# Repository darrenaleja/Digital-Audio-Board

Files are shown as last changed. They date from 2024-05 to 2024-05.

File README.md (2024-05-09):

# Digital Audio Board

## Table of Contents

- [Branch Information](#branch-information)
- [Project Overview](#project-overview)
- [PCB Design Highlights](#pcb-design-highlights)

## Branch Information

- **improvements**: Ongoing updates and enhancements to the initial PCB design are made in this branch. It includes comprehensive revisions in terms of circuit design and layout optimizations.
- **old-iteration**: This branch hosts the original PCB files that were submitted for manufacturing. It represents the first complete design iteration of the audio board.

## Project Overview

I developed this digital audio board to handle and playback digital audio. This repository contains the circuit design, PCB project, datasheets, and detailed documentation needed to understand the digital audio processing workflow implemented.

<p align="center">
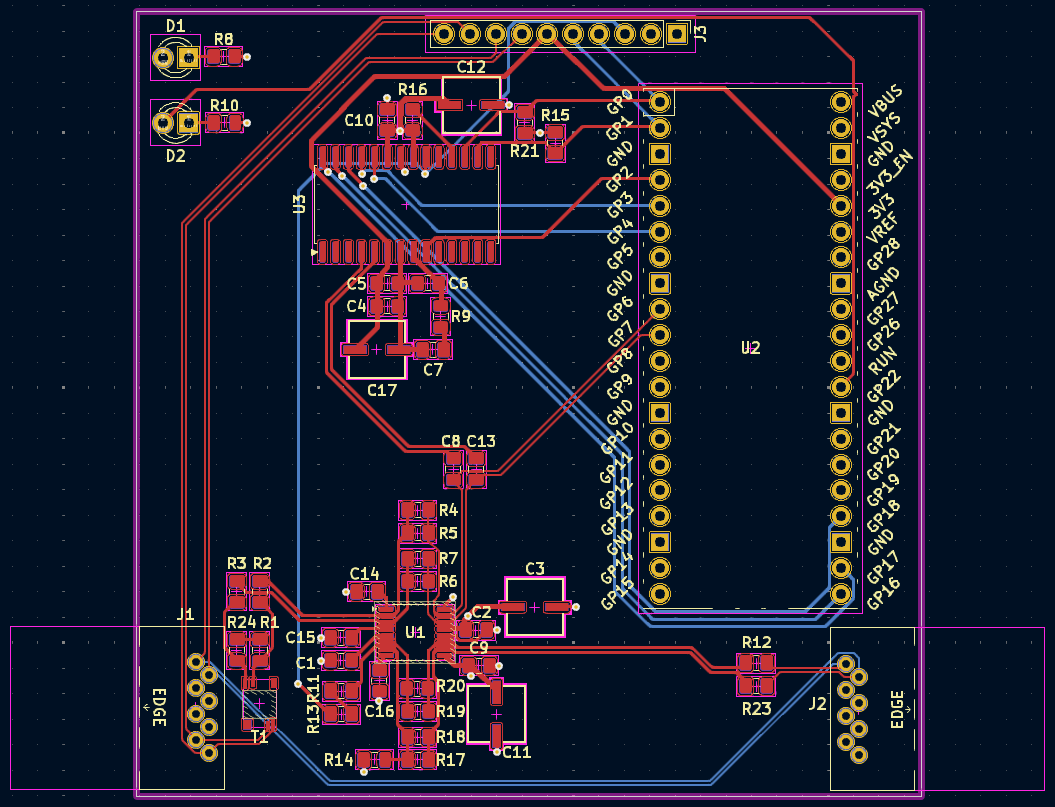
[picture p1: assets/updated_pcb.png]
  
  <br>
  <em>Improved iteration of PCB design</em>
</p>

This board processes AES3 differential audio signals using a number of components that ensure high-quality audio output:
1. **Receiving AES3 Signal**: Captures AES3 differential audio known for its high reliability and quality in professional audio transmission.
2. **Signal Buffering**: Utilizes a THS4522 buffer op-amp to maintain signal integrity as it feeds into the decoding stage.
3. **Digital Audio Decoding**: The CS8416 digital audio interface receiver decodes the buffered AES3 signal into an I2S digital audio format, supporting various digital audio formats with flexible interfacing.
4. **Microcontroller Processing**: A Raspberry Pi Pico microcontroller converts the I2S signal into a PWM output suitable for driving a speaker and manages I2C control signals for dynamic decoder control.
5. **Audio Output**: Outputs audio through a speaker using the PWM signal generated by the Raspberry Pi Pico.
6. **Signal Passing**: Outputs a single-ended signal from the CS8416 back into the THS4522 for onward transmission, enhancing system flexibility.

<p align="center">
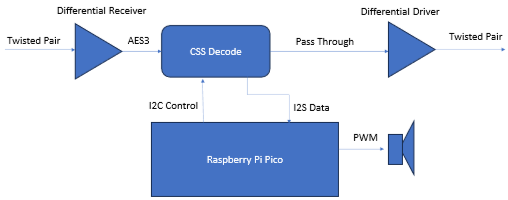
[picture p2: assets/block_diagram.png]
  
  <br>
  <em>Block Diagram of Digital Audio Board</em>
</p>

## PCB Design Highlights

- **Decoupling and Bulk Capacitors**: Incorporates 100nF ceramic decoupling capacitors near IC pins to eliminate high-frequency noise and 10uF aluminum electrolytic capacitors to stabilize supply voltage, critical for high-gain op-amp operations.
- **Symmetry and DNF Resistors**: Features a symmetrical op-amp layout to equalize signal path lengths, reducing phase shifts and susceptibility to EMI.
- **Power and Ground Plane**: Uses continuous planes to reduce impedance and stabilize a low-noise environment, with  cutouts under the op-amp to prevent unwanted capacitance effects.
- **Differential Pair Traces**: Aligns traces meticulously for differential signals to maintain signal integrity and minimize phase errors and external noise susceptibility.

<p align="center">
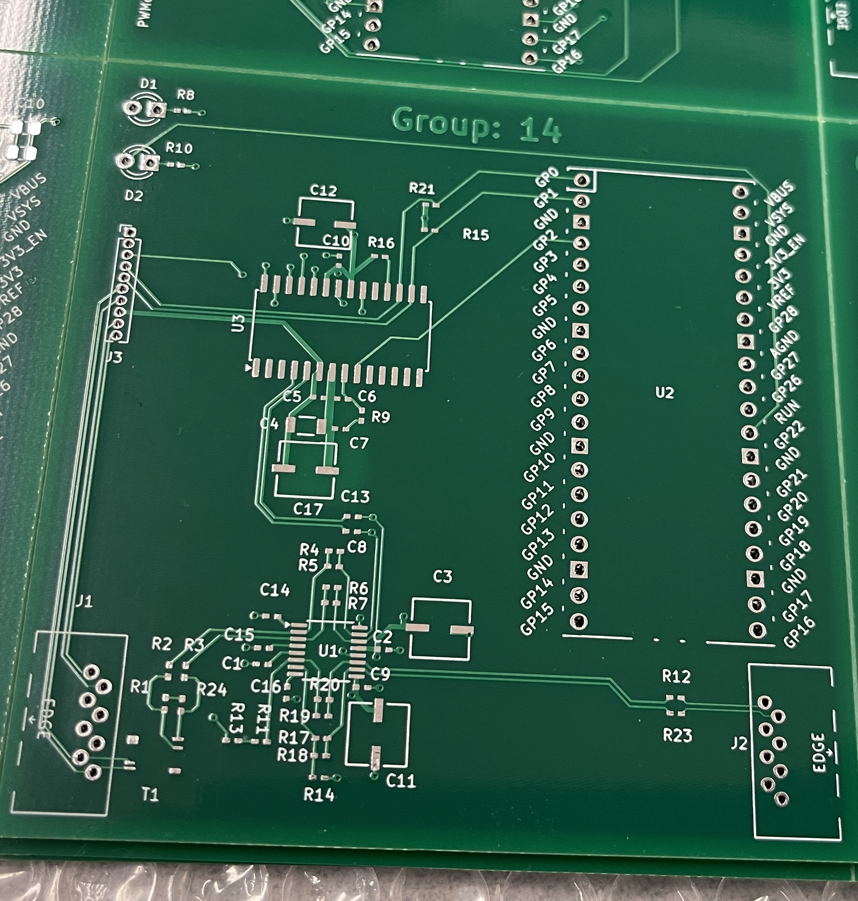
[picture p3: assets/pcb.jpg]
  
  <br>
  <em>Manufactured PCB of initial design</em>
</p>

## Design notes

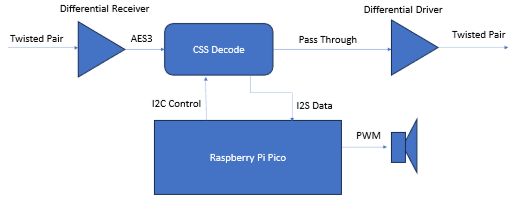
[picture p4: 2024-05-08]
datasheets/block diagram.png

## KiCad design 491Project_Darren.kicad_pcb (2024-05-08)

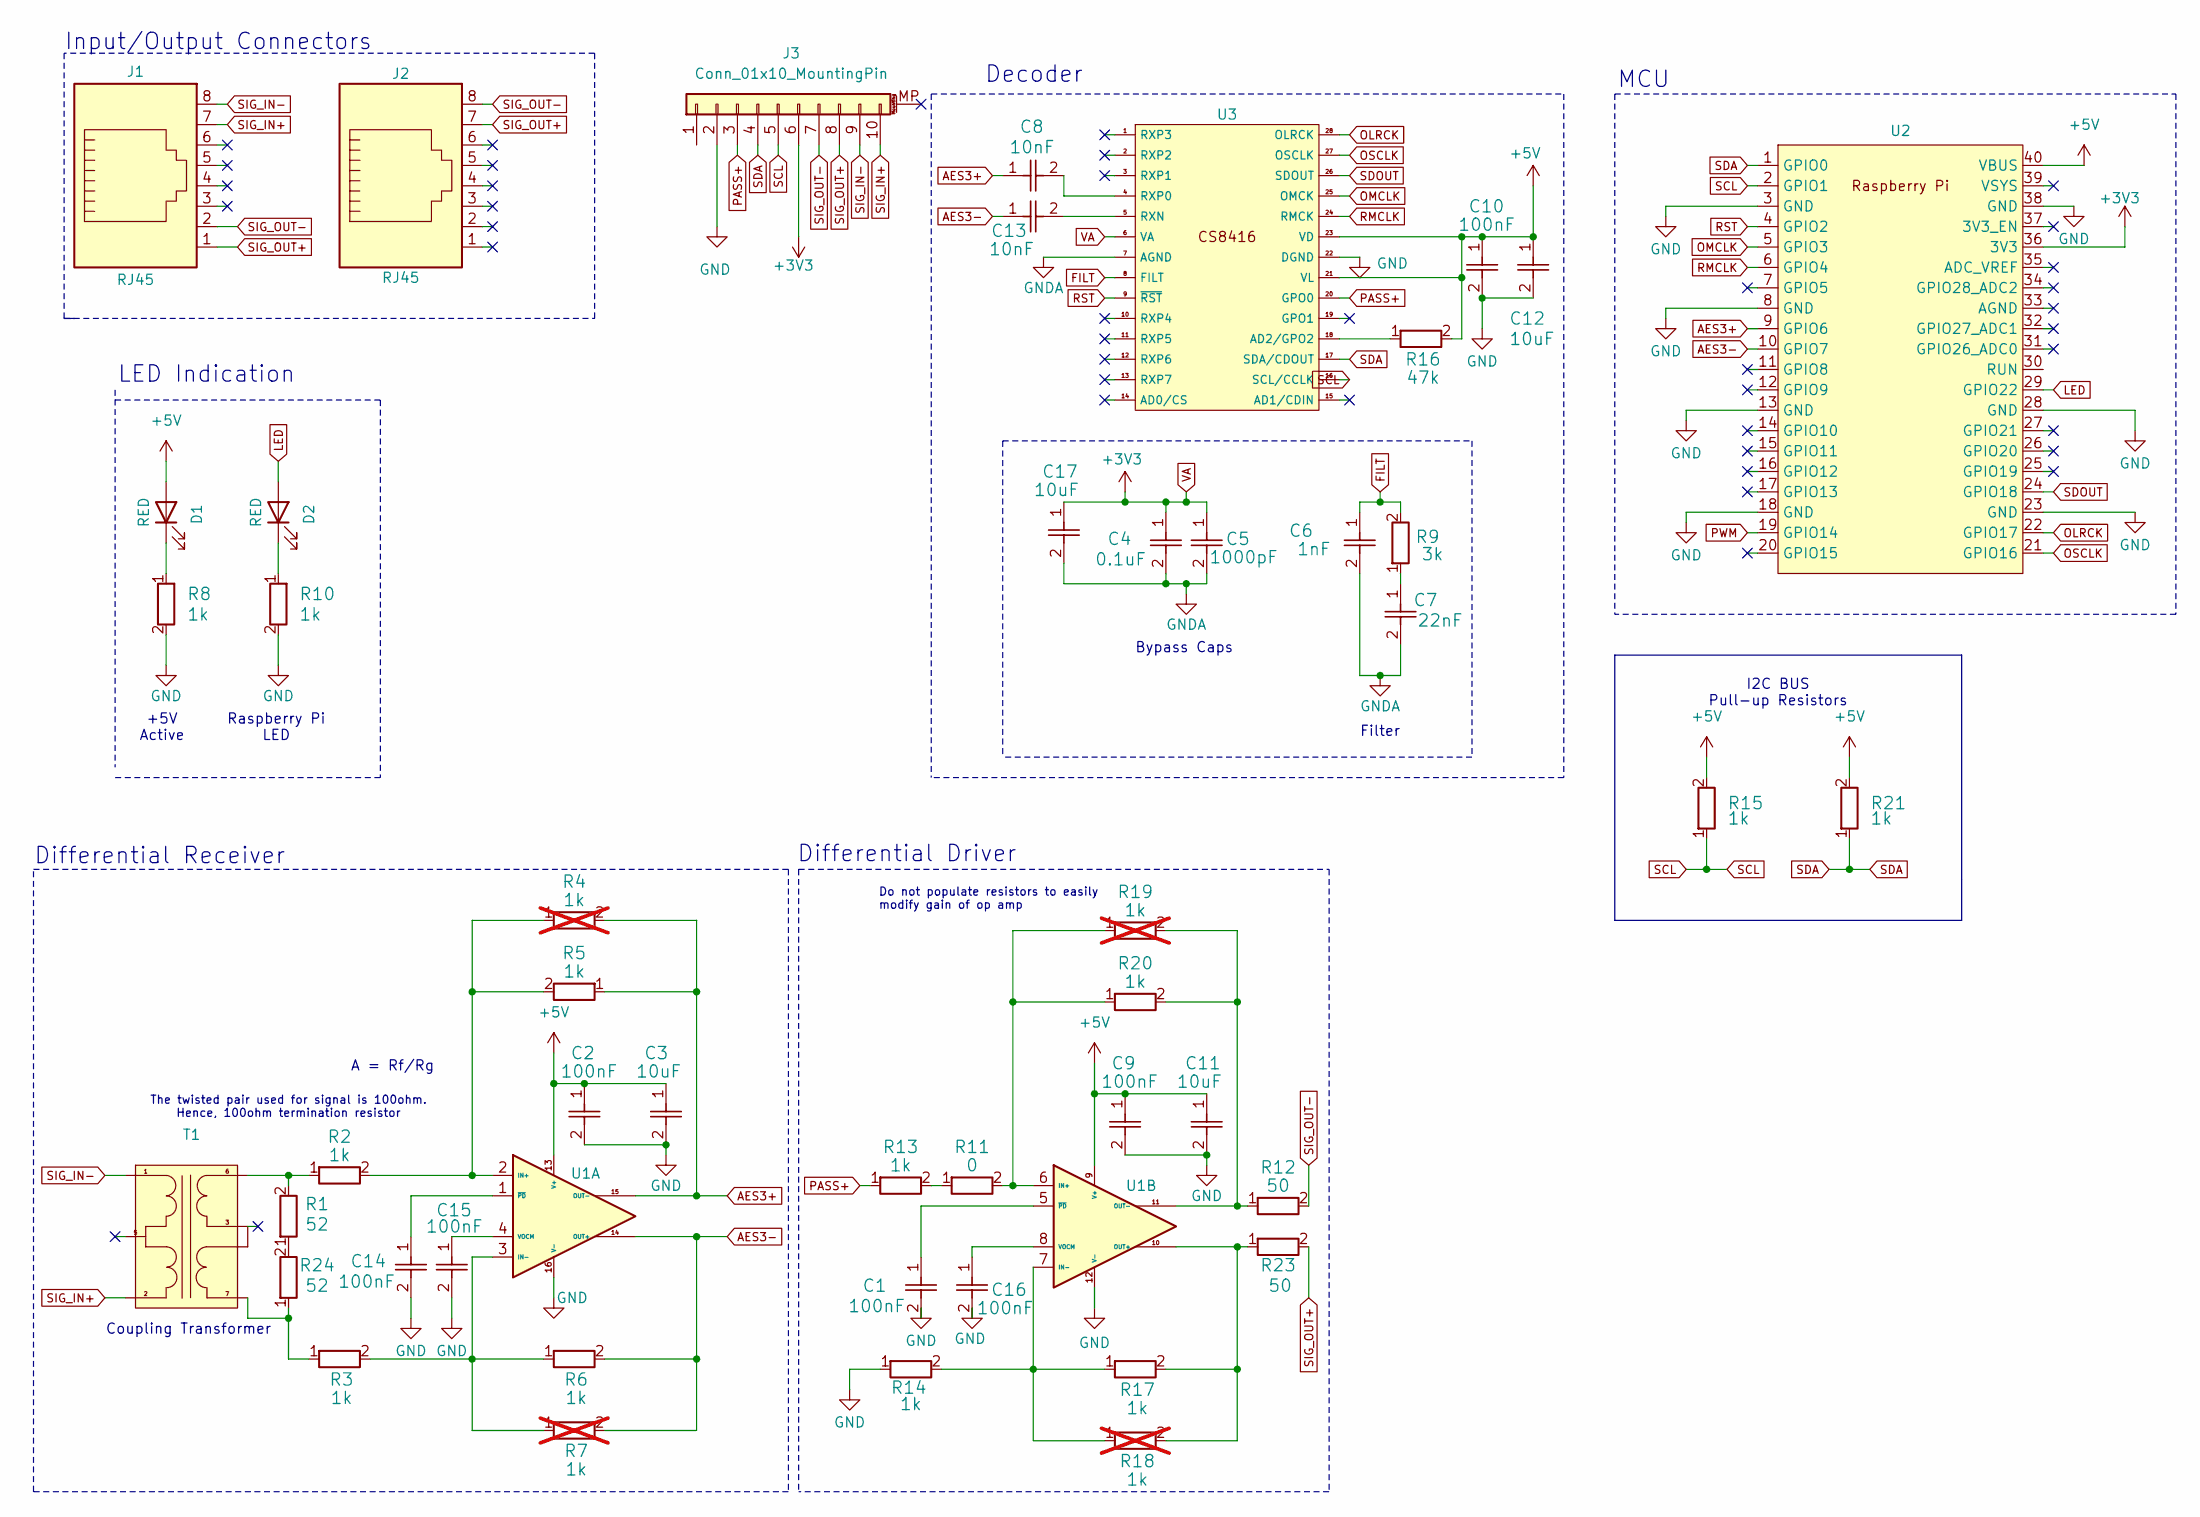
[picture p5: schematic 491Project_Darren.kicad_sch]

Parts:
C1, C2, C9, C10, C14, C15, C16: 100nF; C_0805_2012Metric_Pad1.18x1.45mm_HandSolder
C3, C11, C12, C17: 10uF; CAP_ALUM
C4: 0.1uF; C_0805_2012Metric_Pad1.18x1.45mm_HandSolder
C5: 1000pF; C_0805_2012Metric_Pad1.18x1.45mm_HandSolder
C6: 1nF; C_0805_2012Metric_Pad1.18x1.45mm_HandSolder
C7: 22nF; C_0805_2012Metric_Pad1.18x1.45mm_HandSolder
C8, C13: 10nF; C_0805_2012Metric_Pad1.18x1.45mm_HandSolder
D1, D2: RED; LED_D3.0mm
J1, J2: RJ45; RJ45_Conn
J3: Conn_01x10_MountingPin; PinHeader_1x10_P2.54mm_Vertical
R1, R24: 52; C_0805_2012Metric_Pad1.18x1.45mm_HandSolder
R2, R3, R5, R6, R8, R10, R13, R14, R15, R17, R20, R21: 1k; C_0805_2012Metric_Pad1.18x1.45mm_HandSolder
R4, R7, R18, R19: 1k; C_0805_2012Metric_Pad1.18x1.45mm_HandSolder; not fitted
R9: 3k; C_0805_2012Metric_Pad1.18x1.45mm_HandSolder
R11: 0; C_0805_2012Metric_Pad1.18x1.45mm_HandSolder
R12, R23: 50; C_0805_2012Metric_Pad1.18x1.45mm_HandSolder
R16: 47k; C_0805_2012Metric_Pad1.18x1.45mm_HandSolder
T1: SM453230-181N7Y
U1: TSSOP-16_4.4x5mm_P0.65mm
U2: Pico W
U3: SOIC-28W_7.5x17.9mm_P1.27mm

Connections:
+5V: C2.1, C3.1, C9.1, C10.1, C11.1, C12.1, D1.2 (A), R15.2, R16.2, R21.2, U1.9 (V+), U1.13 (V+), U2.40 (VBUS), U3.21 (VL), U3.23 (VD)
AES3+: C8.1, R4.2, R5.1, U1.15 (OUT-), U2.9 (GPIO6)
AES3-: C13.1, R6.2, R7.2, U1.14 (OUT+), U2.10 (GPIO7)
FILT: C6.1, R9.2, U3.8 (FILT)
GND: C1.2, C2.2, C3.2, C9.2, C10.2, C11.2, C12.2, C14.2, C15.2, C16.2, J3.2, R8.2, R10.2, R14.1, U1.12 (V-), U1.16 (V-), U2.3 (GND), U2.8 (GND), U2.13 (GND), U2.18 (GND), U2.23 (GND), U2.28 (GND), U2.38 (GND), U3.22 (DGND)
GNDA: C4.2, C5.2, C6.2, C7.2, C17.2, U3.7 (AGND)
LED: D2.2 (A), U2.29 (GPIO22)
unnamed: C7.1, R9.1
unnamed: D1.1 (K), R8.1
unnamed: D2.1 (K), R10.1
unnamed: R1.1, R24.2
unnamed: R1.2, R2.1, T1.6
unnamed: R11.1, R13.2
unnamed: R3.1, R24.1, T1.7
unnamed: R2.2, R4.1, R5.2, U1.2 (IN+)
unnamed: R3.2, R6.1, R7.1, U1.3 (IN-)
unnamed: C15.1, U1.4 (VOCM)
unnamed: C14.1, U1.1 (~PD)
unnamed: R11.2, R19.1, R20.1, U1.6 (IN+)
unnamed: R14.2, R17.1, R18.1, U1.7 (IN-)
unnamed: R17.2, R18.2, R23.1, U1.10 (OUT+)
unnamed: R12.1, R19.2, R20.2, U1.11 (OUT-)
unnamed: C16.1, U1.8 (VOCM)
unnamed: C1.1, U1.5 (~PD)
unnamed: R16.1, U3.18 (AD2/GPO2)
unnamed: C13.2, U3.5 (RXN)
unnamed: C8.2, U3.4 (RXP0)
OLRCK: U2.22 (GPIO17), U3.28 (OLRCK)
OMCLK: U2.5 (GPIO3), U3.25 (OMCK)
OSCLK: U2.21 (GPIO16), U3.27 (OSCLK)
PASS+: J3.3, R13.1, U3.20 (GPO0)
PWM: U2.19 (GPIO14)
RMCLK: U2.6 (GPIO4), U3.24 (RMCK)
RST: U2.4 (GPIO2), U3.9 (~RST)
SCL: J3.5, R15.1, U2.2 (GPIO1), U3.16 (SCL/CCLK)
SDA: J3.4, R21.1, U2.1 (GPIO0), U3.17 (SDA/CDOUT)
SDOUT: U2.24 (GPIO18), U3.26 (SDOUT)
SIG_IN+: J1.7, J3.10, T1.2
SIG_IN-: J1.8, J3.9, T1.1
SIG_OUT+: J1.1, J2.7, J3.8, R23.2
SIG_OUT-: J1.2, J2.8, J3.7, R12.2
VA: C4.1, C5.1, C17.1, J3.6, U2.36 (3V3), U3.6 (VA)

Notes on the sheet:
Differential Receiver
Raspberry Pi LED
Decoder
Differential Driver
Coupling Transformer
The twisted pair used for signal is 100ohm. Hence, 100ohm termination resistor
Input/Output Connectors
+5V Active
Filter
A = Rf/Rg
MCU
I2C BUS Pull-up Resistors
Do not populate resistors to easily modify gain of op amp
LED Indication
Bypass Caps

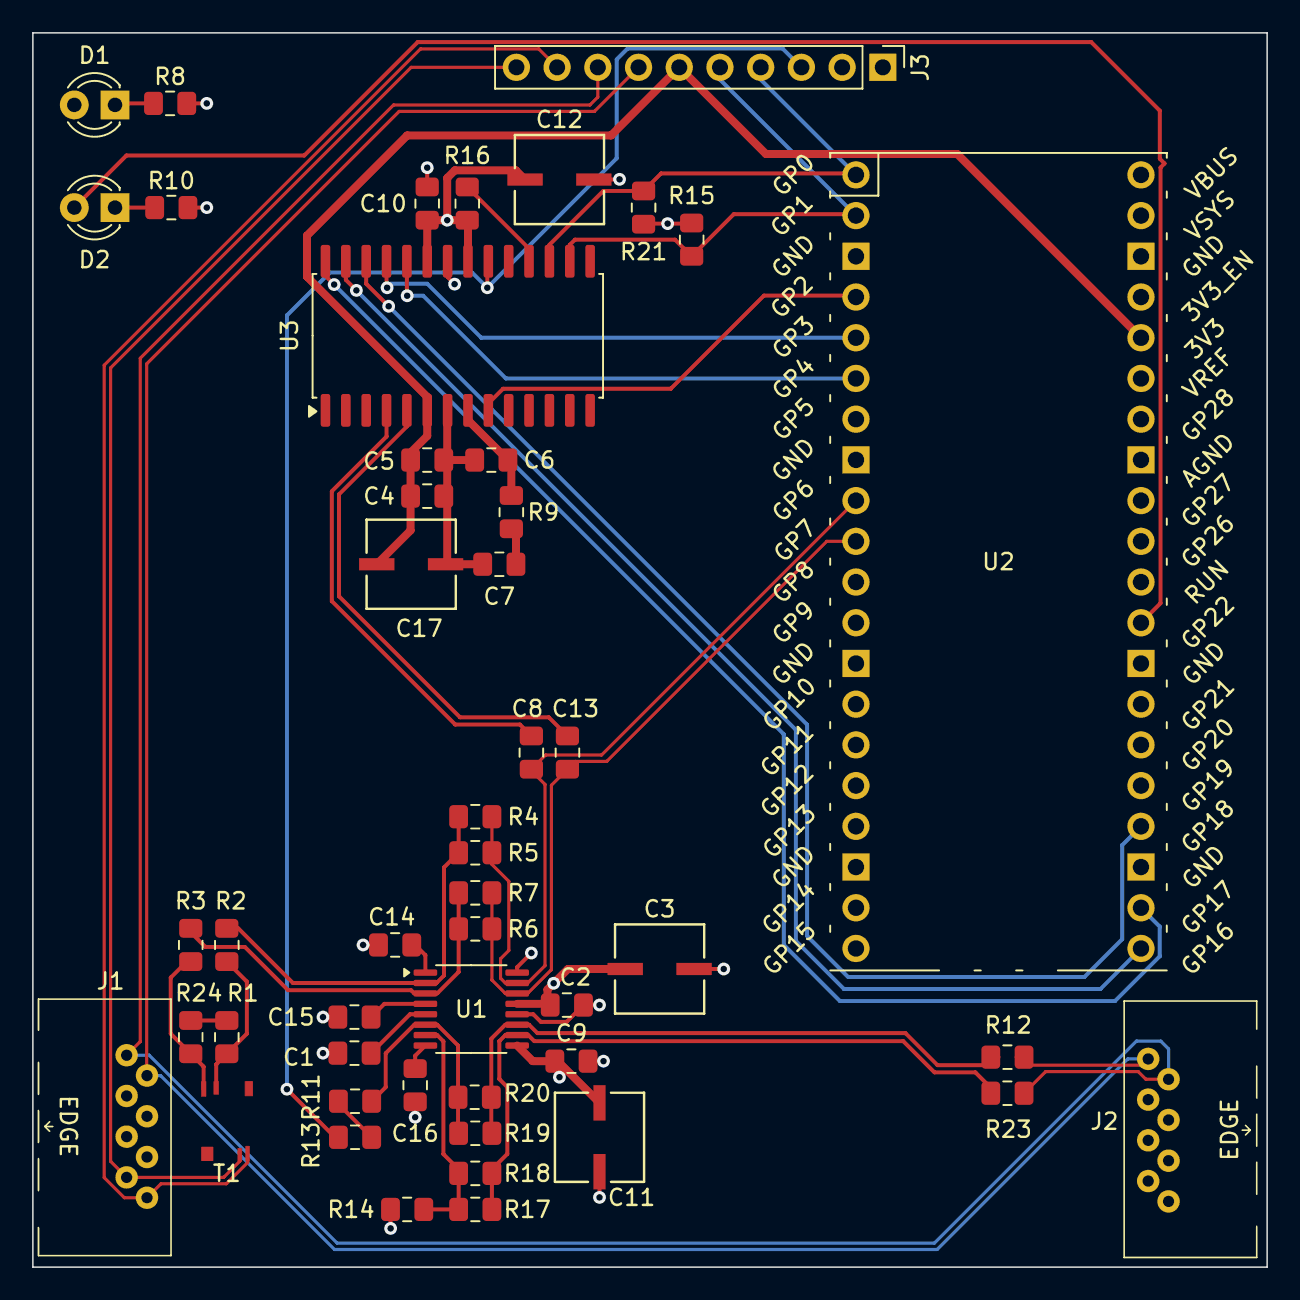
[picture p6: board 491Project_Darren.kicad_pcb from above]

Board: 4 copper layers, 77.0 x 77.0 mm, 49 parts (0 on the bottom side), 41 nets.

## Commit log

2024-01-26 Update Test Script.py
    Testing each pin voltage
2024-02-07 Add files via upload
    Excel file of data recorded during lab one
    [MSE 491 Adv Elec Lab 1.xlsx]
2024-03-08 Project Initiated
    [Template.kicad_pcb, Template.kicad_sch]
2024-03-09 mar 9
    [Template.kicad_sch]
2024-03-09 Group 15
    [Group15_DAB.kicad_pcb, Template.kicad_sch]
2024-03-14 pi day push
    [Template.kicad_sch]
2024-03-15 Lab Jordan Reviewed kinda
    Pls add pull up resistors!!!!
    [Group15_DAB.kicad_sch]
2024-03-20 Added Test Pins
    [491Project_Darren.kicad_sch]
2024-03-21 before lab push
    [491Project_Darren.kicad_pcb]
2024-03-22 Post lab
    remember to keep differential pairs close together
    [491Project_Darren.kicad_pcb, 491Project_Darren.kicad_sch]
2024-03-26 Added Power planes, Removed dead copper?
    [491Project_Darren.kicad_pcb, 491Project_Darren.kicad_sch]
2024-03-31 fix cutouts
    [491Project_Darren.kicad_pcb, 491Project_Darren.kicad_sch]
2024-04-13 Remove lab file and remove unnecessary files
    [491Project_Darren.kicad_pcb, 491Project_Darren.kicad_sch, MSE 491 Adv Elec Lab 1.xlsx]
2024-04-13 Updated footprints to 0603
2024-04-18 changes 0402 footprints to 0805
    [491Project_Darren.kicad_pcb, 491Project_Darren.kicad_sch]
2024-05-08 updated silkscreen text to 40 mils
    [491Project_Darren.kicad_pcb, 491Project_Darren.kicad_sch]
2024-05-08 Updated silkscreen
    [491Project_Darren.kicad_pcb]
